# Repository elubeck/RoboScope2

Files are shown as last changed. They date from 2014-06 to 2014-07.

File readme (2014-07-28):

Steps for installing

Jython Plugin
- Jython standalone jar file (v2.7b1 tested) needs to be moved to /plugins/Micro-Manager
- JythonMMPlugin.jar (tested with jython v.27b1 and Micro-Manager-1.4.17,1.4.18) needs to be moved to /mmplugins/
- jythonconsole directory needs to be moved to /plugins/Micro-Manager

If all this works you should see a jython console in the plugins dropdown in micromanager.  If should open and run just fine.
In the future this should be replaced by ipython.  It'll make debugging easier.

The firmware should be uploaded

Notes:
    - Tried jython v2.7b2.  Didn't work.

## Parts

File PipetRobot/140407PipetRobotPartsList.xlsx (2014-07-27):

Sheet: Digikey
what | catalog no | how many | from where | how much each | total
3d printer fan | 1053-1208-ND | 4 | digikey | 9.98 | 39.92

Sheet: Mcmaster
what | catalog no | how many | from where | how much each | total
M3 6mm | 94500A221 | 1 | mcmaster | 5.77 | 5.77
M3 8mm | 94500A222 | 1 | mcmaster | 5.9 | 5.9
M5 10mm | 92095A208 | 1 | mcmaster | 11.98 | 11.98
M4 10mm | 94500A227 | 1 | mcmaster | 7.54 | 7.54
M6 | 92095A224 | 1 | mcmaster | 8.5 | 8.5
washer | 91090A108 | 1 | mcmaster | 3.9 | 3.9
20mm double | 5537T111 6 ft | 1 | mcmaster | 26.1 | 26.1
20mm double | 5537T111 2 ft | 1 | mcmaster | 11.23 | 11.23
1/4 in shaft 9" | 6061K21 | 2 | mcmaster | 4.55 | 9.1
3/8 shaft 1 ft | 6061K32 | 2 | mcmaster | 6.18 | 12.36
3/8 shaft 16" | 6061K424 | 2 | mcmaster | 9.16 | 18.32
1/4 bushing | 6381K415 | 3 | mcmaster | 1.48 | 4.44
3/8 bushing | 6381K453 | 6 | mcmaster | 1.88 | 11.28
20 mm single | 5537T101 6 ft | 1 | mcmaster | 17.19 | 17.19
 |  |  |  | total | 110.02

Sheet: Amazon
what | catalog no | how many | from where | how much each | total
endstops | B00G2E6UZC | 1 | amazon | 11 | 11
gt2 pulley | B00GNWMTWG | 3 | amazon | 5.8 | 17.4
gt2 belt 5m | B00F2IQNX8 | 1 | amazon | 20 | 20
nema 17 | B00C4P382G | 3 | amazon | 22 | 66
24v power supply | B00IF93H6W | 1 | amazon | 46 | 46
1/8" aluminum sheet | B00BO78RCQ | 1 | amazon | 11.52 | 11.52
 |  |  |  | total | 171.92

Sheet: Adafruit
what | catalog no | how many | from where | how much each | total
t nuts | 1158 | 2 | adafruit | 9.95 | 19.9

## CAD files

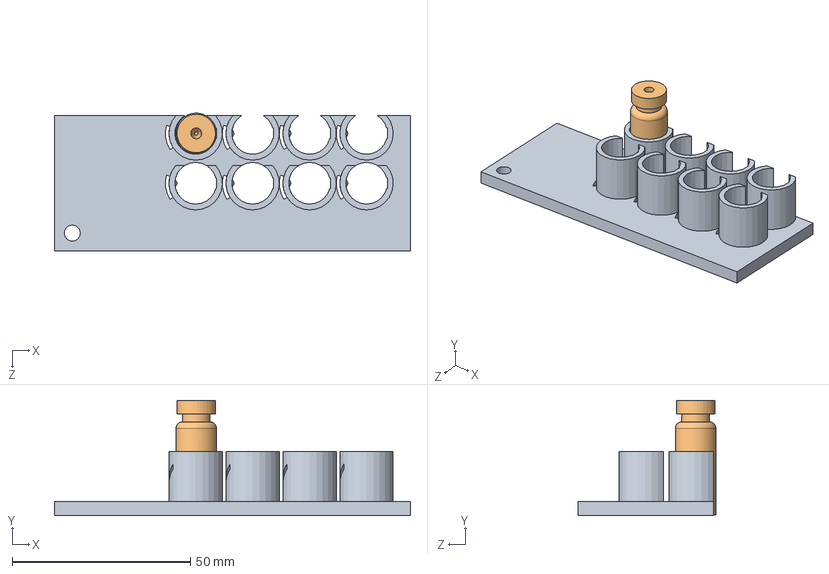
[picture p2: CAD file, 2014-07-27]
PipetRobot/vialholder/Assem1.SLDASM
100.0 x 32.3 x 38.7 mm
vialrack
plasticvial

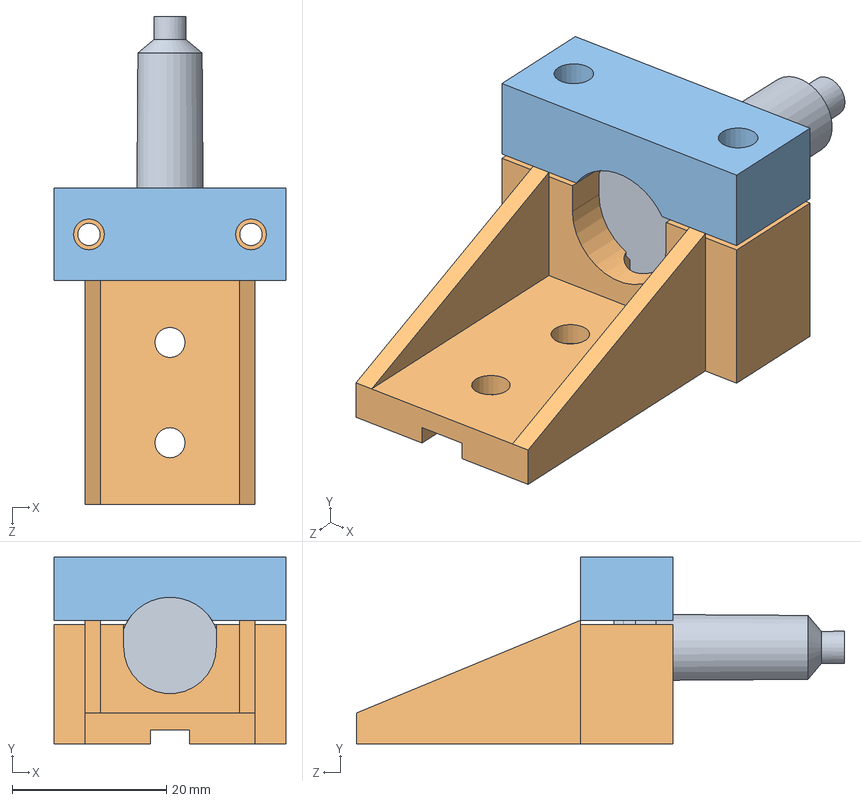
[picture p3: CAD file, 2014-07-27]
PipetRobot/syringe/purplecolumnholder.SLDASM
30.0 x 24.2 x 63.2 mm
qiagen_purple_column
purpleColumnHolder
purplecolumnclamper

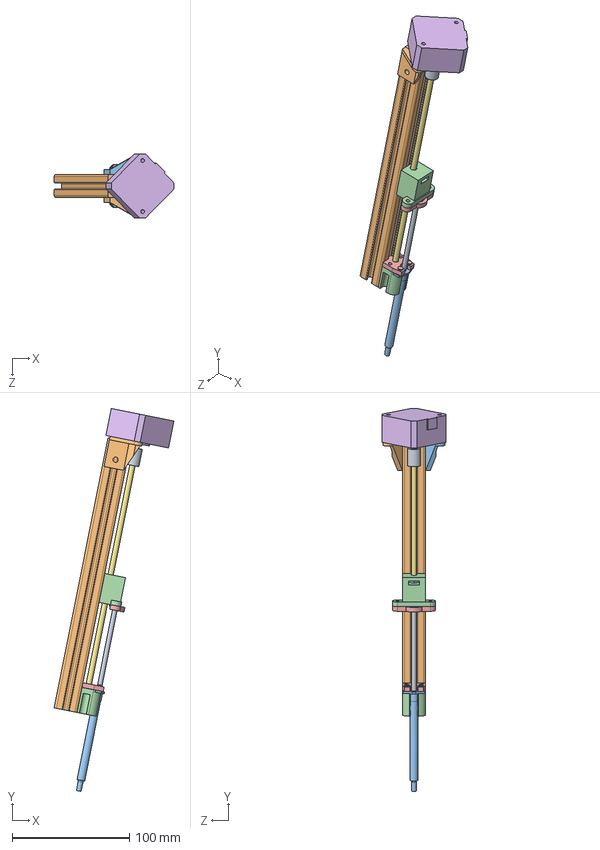
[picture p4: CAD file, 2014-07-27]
PipetRobot/syringe/syringeassembly.SLDASM
102.1 x 326.2 x 54.4 mm
syringeplunger
AluminumExtrusion
1mlsyringe
syringeholderbottom
syringeholdertop
smallstepper
Part3^syringeassembly
Part2^syringeassembly x 2
Part6^syringeassembly
Part7^syringeassembly
MirrorPart7^syringeassembly
pistonholder
Part1^syringeassembly

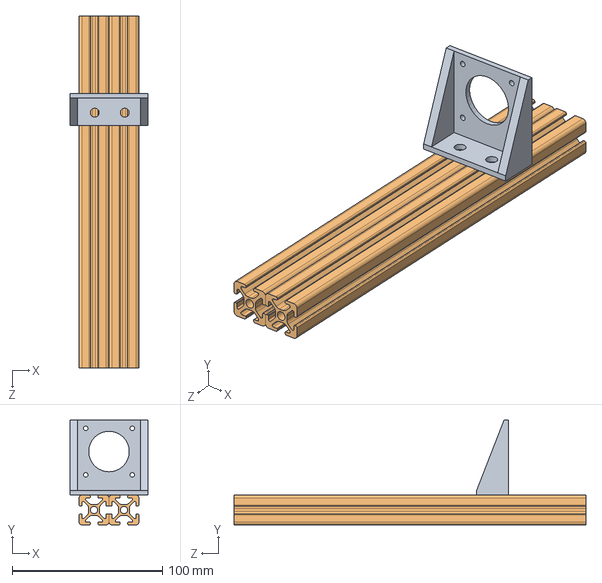
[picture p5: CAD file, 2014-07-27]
PipetRobot/Assem2.SLDASM
52.0 x 70.0 x 234.6 mm
steppermountlonger
AluminumExtrusion x 2

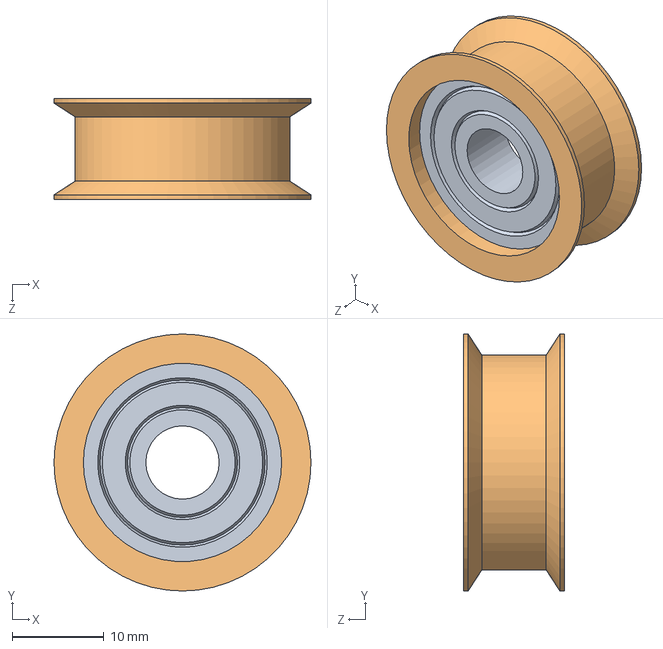
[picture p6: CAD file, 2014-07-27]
PipetRobot/skatepulley.SLDASM
28.0 x 28.0 x 11.0 mm
SkateBearing
skatepulley

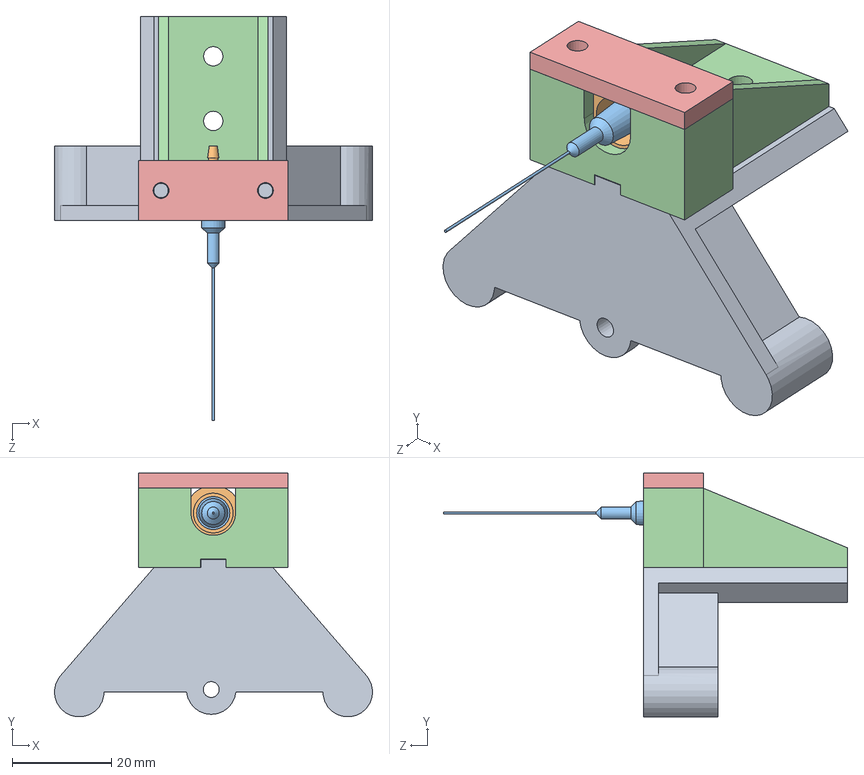
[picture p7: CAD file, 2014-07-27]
PipetRobot/syringe/Assem1.SLDASM
64.0 x 49.0 x 81.3 mm
zsyringemount
needleluer
needle
luerholder
luerholderclamp

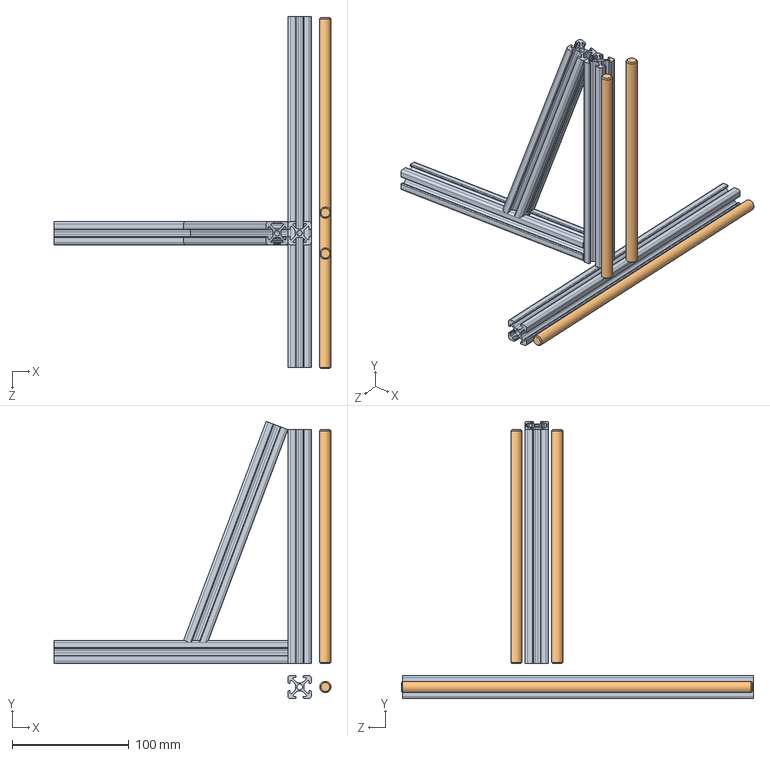
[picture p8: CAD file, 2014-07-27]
PipetRobot/Robot.SLDASM
236.8 x 237.0 x 301.0 mm
AluminumExtrusion x 4
ThreeEighthsRod x 3

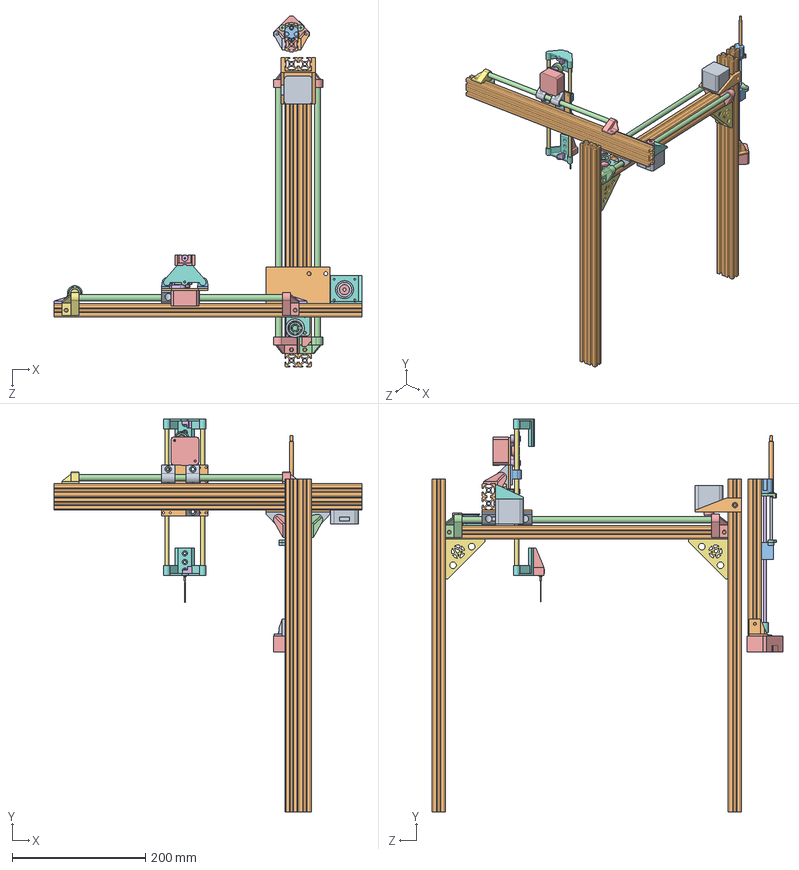
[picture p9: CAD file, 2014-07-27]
PipetRobot/autopettor.SLDASM
462.0 x 589.9 x 527.1 mm
NEMA17 x 2
AluminumExtrusion x 9
BronzeBushing x 6
ThreeEighthsRod x 4
CornerRodClamp x 4
Part4^autopettor x 2
quarterInchShaft9in x 2
quarterInchBearing x 3
bearingmountflat x 6
Part8^autopettor
Part9^autopettor x 3
SkateBearing x 4
GT2pulley x 3
Part12^autopettor
CornerRodClampCutout
steppermount
beltTrap
steppermountlonger
beltTrapTop
CornerRodClampWithTensioner
beltTrapTensioner
beltTrapTensioner2 x 3
Part3^autopettor x 4
zsyringemount x 2
syringeplunger
1mlsyringe
syringeholderbottom
syringeholdertop
smallstepper x 2
Part3^syringeassembly
Part2^syringeassembly x 2
Part6^syringeassembly
Part7^syringeassembly
MirrorPart7^syringeassembly
pistonholder
Part1^syringeassembly
luerholder
needleluer
needle
Part1^autopettor
skatepulley
Part2^autopettor

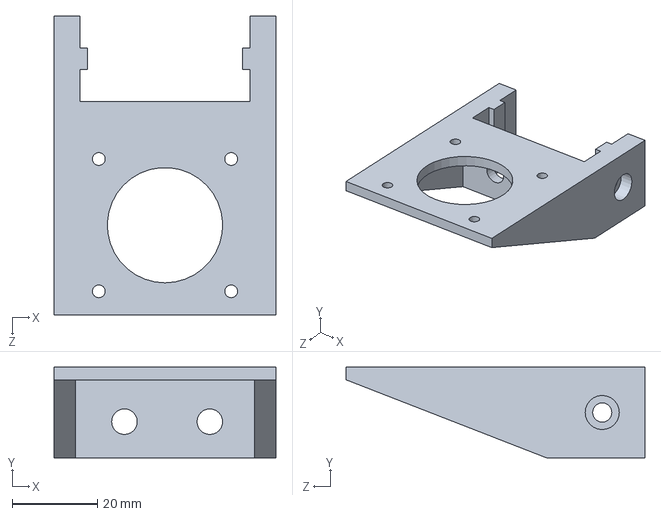
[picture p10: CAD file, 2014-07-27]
PipetRobot/steppermountlonger.sldprt
52.0 x 21.3 x 70.0 mm

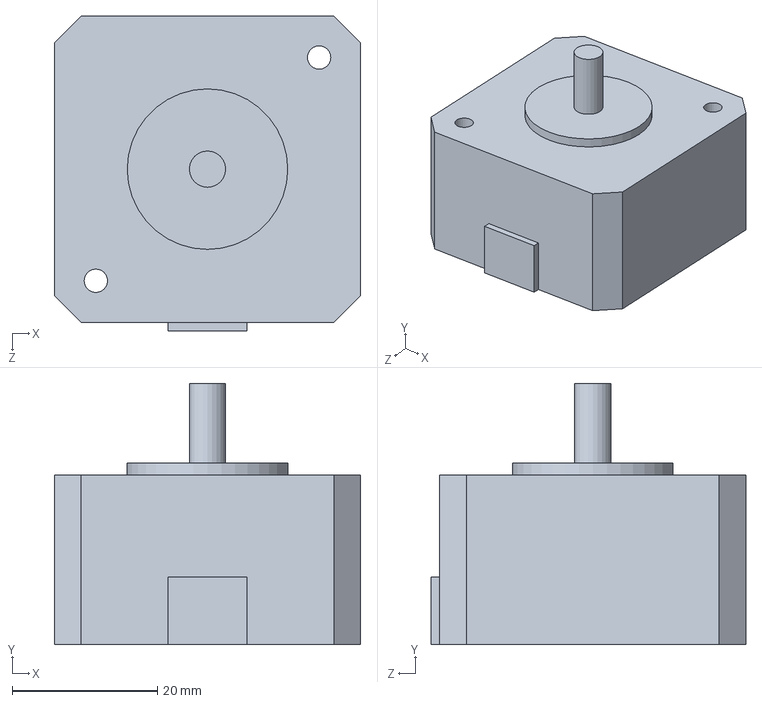
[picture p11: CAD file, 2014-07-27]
PipetRobot/syringe/smallstepper.SLDPRT
42.2 x 36.0 x 43.4 mm

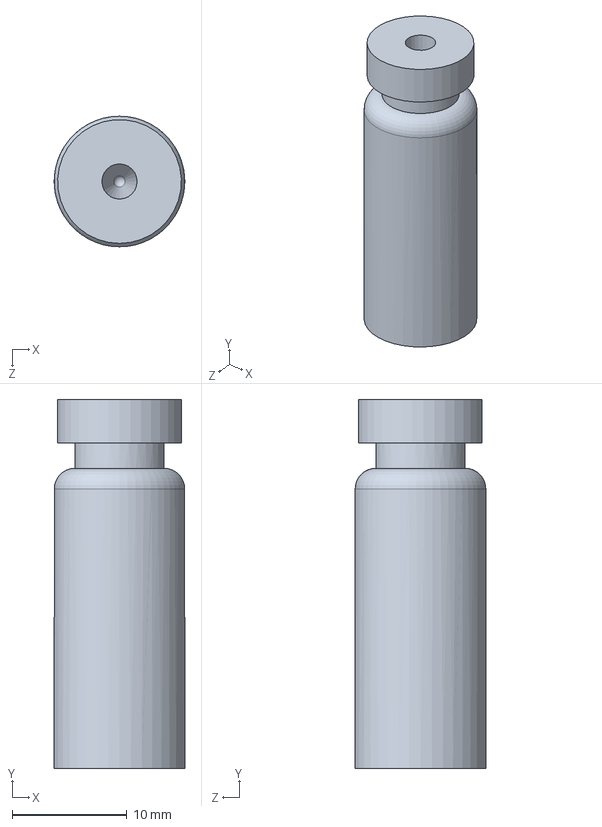
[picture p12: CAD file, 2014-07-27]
PipetRobot/vialholder/plasticvial.SLDPRT
11.4 x 32.2 x 11.4 mm

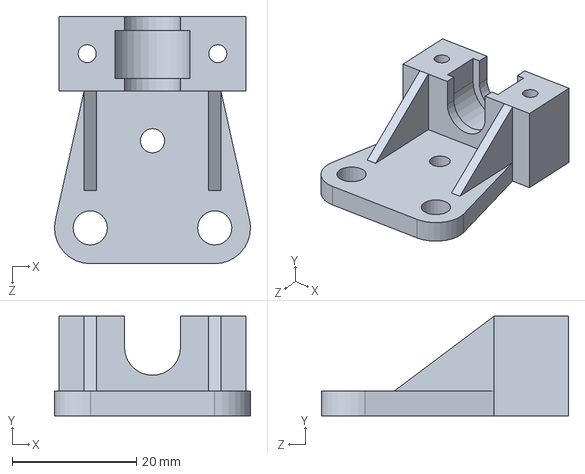
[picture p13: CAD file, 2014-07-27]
PipetRobotv2/luerholdershapeoko.sldprt
31.5 x 16.0 x 39.8 mm

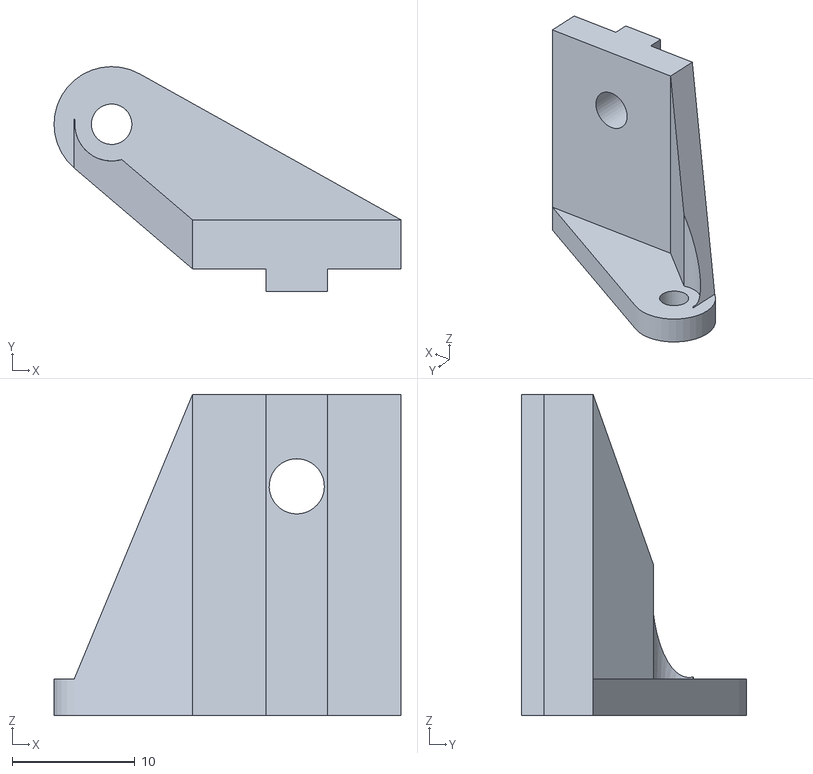
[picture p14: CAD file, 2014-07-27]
PipetRobot/syringe/Mirrorsteppermount.STL
28.3 x 18.3 x 26.2

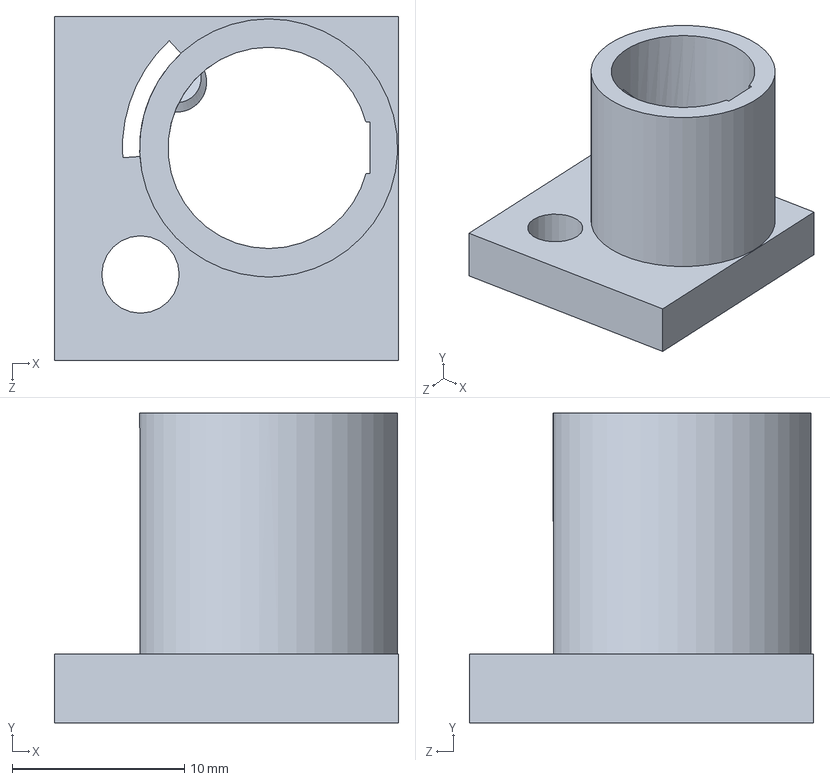
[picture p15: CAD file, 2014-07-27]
PipetRobot/vialholder/vialracksingle.SLDPRT
20.0 x 18.0 x 20.0 mm

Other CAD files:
PipetRobot/NeedleLuerHolder.sldasm
PipetRobot/steppermount.sldprt
PipetRobot/xaxisbearing.STL
PipetRobot/bearingmountflat.sldprt
PipetRobot/5537T104.SLDPRT
PipetRobot/57105K13pulley.SLDPRT
PipetRobot/AluminumExtrusion.sldprt
PipetRobot/CornerRodClamp.sldprt
PipetRobot/CornerRodClampCutout.sldprt
PipetRobot/CornerRodClampWithTensioner.sldprt
PipetRobot/GT2pulley.sldprt
PipetRobot/Imported Components/NeedleLuerHolder/luerholder.ipt
PipetRobot/ThreeEighthsRod.sldprt
PipetRobot/bearingmount.sldprt
PipetRobot/beltTrap.sldprt
PipetRobot/beltTrapTensioner.STL
PipetRobot/beltTrapTensioner.sldprt
PipetRobot/beltTrapTensioner2.sldprt
PipetRobot/beltTrapTop.STL
PipetRobot/beltTrapTop.sldprt
PipetRobot/beltTrapmid.STL
PipetRobot/epP200.SLDPRT
PipetRobot/m3screw.SLDPRT
PipetRobot/pulleymount.STL
PipetRobot/quarterInchBearing.sldprt
PipetRobot/quarterInchShaft9in.sldprt
PipetRobot/rainP200.SLDPRT
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

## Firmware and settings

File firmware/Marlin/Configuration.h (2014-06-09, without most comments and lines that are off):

#define CONFIGURATION_H
#define STRING_VERSION_CONFIG_H __DATE__ " " __TIME__ // build date and time
#define STRING_CONFIG_H_AUTHOR "(none, default config)" // Who made the changes.
#define SERIAL_PORT 0
#define BAUDRATE 115200
#define MOTHERBOARD 65
#define EXTRUDERS 1
#define POWER_SUPPLY 1
#define TEMP_SENSOR_0 0
#define TEMP_SENSOR_1 0
#define TEMP_SENSOR_2 0
#define TEMP_SENSOR_BED 0
#define MAX_REDUNDANT_TEMP_SENSOR_DIFF 10
#define TEMP_RESIDENCY_TIME 10  // (seconds)
#define TEMP_HYSTERESIS 3       // (degC) range of +/- temperatures considered "close" to the target one
#define TEMP_WINDOW     1       // (degC) Window around target to start the residency timer x degC early.
#define HEATER_0_MINTEMP 0
#define HEATER_1_MINTEMP 5
#define HEATER_2_MINTEMP 5
#define BED_MINTEMP 0
#define HEATER_0_MAXTEMP 800
#define HEATER_1_MAXTEMP 275
#define HEATER_2_MAXTEMP 275
#define BED_MAXTEMP 300
#define BANG_MAX 255 // limits current to nozzle while in bang-bang mode; 255=full current
#define PID_MAX 20 // limits current to nozzle while PID is active (see PID_FUNCTIONAL_RANGE below); 255=full current
#define MAX_BED_POWER 100 // limits duty cycle to bed; 255=full current
#define EXTRUDE_MINTEMP 0
#define EXTRUDE_MAXLENGTH (X_MAX_LENGTH+Y_MAX_LENGTH) //prevent extrusion of very large distances.
#define ENDSTOPPULLUPS // Comment this out (using // at the start of the line) to disable the endstop pullup resistors
  #define ENDSTOPPULLUP_XMAX
  #define ENDSTOPPULLUP_YMAX
  #define ENDSTOPPULLUP_ZMAX
  #define ENDSTOPPULLUP_XMIN
  #define ENDSTOPPULLUP_YMIN
  #define ENDSTOPPULLUP_ZMIN
const bool X_MIN_ENDSTOP_INVERTING = true; // set to true to invert the logic of the endstop.
const bool Y_MIN_ENDSTOP_INVERTING = true; // set to true to invert the logic of the endstop.
const bool Z_MIN_ENDSTOP_INVERTING = true; // set to true to invert the logic of the endstop.
const bool X_MAX_ENDSTOP_INVERTING = true; // set to true to invert the logic of the endstop.
const bool Y_MAX_ENDSTOP_INVERTING = true; // set to true to invert the logic of the endstop.
const bool Z_MAX_ENDSTOP_INVERTING = true; // set to true to invert the logic of the endstop.
const bool E_MIN_ENDSTOP_INVERTING = true; //dreyedit
#if defined(COREXY) && !defined(DISABLE_MAX_ENDSTOPS)
  #define DISABLE_MAX_ENDSTOPS
#endif
#define X_ENABLE_ON 0
#define Y_ENABLE_ON 0
#define Z_ENABLE_ON 0
#define E_ENABLE_ON 0 // For all extruders
#define DISABLE_X false
#define DISABLE_Y false
#define DISABLE_Z false
#define DISABLE_E false // For all extruders
#define INVERT_X_DIR false    // for Mendel set to false, for Orca set to true
#define INVERT_Y_DIR false    // for Mendel set to true, for Orca set to false
#define INVERT_Z_DIR true     // for Mendel set to false, for Orca set to true
#define INVERT_E0_DIR true   // for direct drive extruder v9 set to true, for geared extruder set to false
#define INVERT_E1_DIR false    // for direct drive extruder v9 set to true, for geared extruder set to false
#define INVERT_E2_DIR false   // for direct drive extruder v9 set to true, for geared extruder set to false
#define X_HOME_DIR -1
#define Y_HOME_DIR -1
#define Z_HOME_DIR 1
#define E_HOME_DIR -1 //home the e axis!! dreyedit
#define min_software_endstops true // If true, axis won't move to coordinates less than HOME_POS.
#define max_software_endstops true  // If true, axis won't move to coordinates greater than the defined lengths below.
#define X_MAX_POS 237
#define X_MIN_POS 0
#define Y_MAX_POS 160
#define Y_MIN_POS 0
#define Z_MAX_POS 86
#define Z_MIN_POS 0
#define X_MAX_LENGTH (X_MAX_POS - X_MIN_POS)
#define Y_MAX_LENGTH (Y_MAX_POS - Y_MIN_POS)
#define Z_MAX_LENGTH (Z_MAX_POS - Z_MIN_POS)
#define ENABLE_AUTO_BED_LEVELING // Delete the comment to enable (remove // at the start of the line)
      #define ABL_PROBE_PT_1_X 51
      #define ABL_PROBE_PT_1_Y 46
      #define ABL_PROBE_PT_2_X 120
      #define ABL_PROBE_PT_2_Y 69
      #define ABL_PROBE_PT_3_X 80
      #define ABL_PROBE_PT_3_Y 92
  #define X_PROBE_OFFSET_FROM_EXTRUDER 0
  #define Y_PROBE_OFFSET_FROM_EXTRUDER 0
  #define Z_PROBE_OFFSET_FROM_EXTRUDER 0
  #define Z_RAISE_BEFORE_HOMING 50       // (in mm) Raise Z before homing (G28) for Probe Clearance.
  #define XY_TRAVEL_SPEED 800         // X and Y axis travel speed between probes, in mm/min
  #define Z_RAISE_BEFORE_PROBING 50    //How much the extruder will be raised before traveling to the first probing point.
  #define Z_RAISE_BETWEEN_PROBINGS 50  //How much the extruder will be raised when traveling from between next probing points
  #define Z_SAFE_HOMING   // This feature is meant to avoid Z homing with probe outside the bed area.
    #define Z_SAFE_HOMING_X_POINT (X_MAX_LENGTH/2)    // X point for Z homing when homing all axis (G28)
    #define Z_SAFE_HOMING_Y_POINT (Y_MAX_LENGTH/2)    // Y point for Z homing when homing all axis (G28)
#define MANUAL_X_HOME_POS 0
#define MANUAL_Y_HOME_POS 0
#define MANUAL_Z_HOME_POS 0
#define NUM_AXIS 4 // The axis order in all axis related arrays is X, Y, Z, E
#define HOMING_FEEDRATE {1000, 1000, 1000, 1000}  // set the homing speeds (mm/min)
#define DEFAULT_AXIS_STEPS_PER_UNIT   {160.476,160.476,320.476,760*1.1}  // default steps per unit for Ultimaker
#define DEFAULT_MAX_FEEDRATE          {500, 500, 500, 500}    // (mm/sec)
#define DEFAULT_MAX_ACCELERATION      {50,100,900,10000}    // X, Y, Z, E maximum start speed for accelerated moves. E default values are good for Skeinforge 40+, for older versions raise them a lot.
#define DEFAULT_ACCELERATION          3000    // X, Y, Z and E max acceleration in mm/s^2 for printing moves
#define DEFAULT_RETRACT_ACCELERATION  3000   // X, Y, Z and E max acceleration in mm/s^2 for retracts
#define DEFAULT_XYJERK                2.0    // (mm/sec)
#define DEFAULT_ZJERK                 20.0// (mm/sec)
#define DEFAULT_EJERK                 5.0    // (mm/sec)
#define CUSTOM_M_CODES
  #define CUSTOM_M_CODE_SET_Z_PROBE_OFFSET 851
  #define Z_PROBE_OFFSET_RANGE_MIN -15
  #define Z_PROBE_OFFSET_RANGE_MAX -5
#define PLA_PREHEAT_HOTEND_TEMP 180
#define PLA_PREHEAT_HPB_TEMP 70
#define PLA_PREHEAT_FAN_SPEED 255   // Insert Value between 0 and 255
#define ABS_PREHEAT_HOTEND_TEMP 240
#define ABS_PREHEAT_HPB_TEMP 100
#define ABS_PREHEAT_FAN_SPEED 255   // Insert Value between 0 and 255
#define FAST_PWM_FAN
#define FAN_SOFT_PWM
#define SOFT_PWM_SCALE 2
#include "Configuration_adv.h"
#include "thermistortables.h"

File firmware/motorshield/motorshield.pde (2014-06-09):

#include <Wire.h>
#include <Adafruit_MotorShield.h>
#include "utility/Adafruit_PWMServoDriver.h"

Adafruit_MotorShield AFMS = Adafruit_MotorShield();
Adafruit_DCMotor *motor1 = AFMS.getMotor(1);
Adafruit_DCMotor *motor2 = AFMS.getMotor(2);
Adafruit_DCMotor *solenoid1 = AFMS.getMotor(3);
Adafruit_DCMotor *solenoid2 = AFMS.getMotor(4);
Adafruit_DCMotor *motor;

int pin = 0;

void setup() {
  Serial.begin(19200);
  AFMS.begin();
  motor1->setSpeed(255);
  motor2->setSpeed(255);
  solenoid1->setSpeed(255);
  solenoid2->setSpeed(255);
}

void loop() {
 while (Serial.available()) {
   int inByte_0 = Serial.read();
   int inByte_1 = Serial.read();
   switch (inByte_0) {
     case 0: motor = motor1;
     case 1: motor = motor2;
     case 2: motor = solenoid1;
     case 3: motor = solenoid2;
   }
   Serial.println(inByte_0 - 48);
   Serial.println(inByte_1);
 } 
}

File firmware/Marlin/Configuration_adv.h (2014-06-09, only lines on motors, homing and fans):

#define CONTROLLERFAN_PIN -1 //Pin used for the fan to cool controller (-1 to disable)
#define EXTRUDER_0_AUTO_FAN_PIN   -1
#define EXTRUDER_1_AUTO_FAN_PIN   -1
#define EXTRUDER_2_AUTO_FAN_PIN   -1
#define ENDSTOPS_ONLY_FOR_HOMING // If defined the endstops will only be used for homing
#define X_HOME_RETRACT_MM 5
#define Y_HOME_RETRACT_MM 5
#define Z_HOME_RETRACT_MM 2
#define MICROSTEP1 LOW,LOW
#define MICROSTEP2 HIGH,LOW
#define MICROSTEP4 LOW,HIGH
#define MICROSTEP8 HIGH,HIGH
#define MICROSTEP16 HIGH,HIGH
#define MICROSTEP_MODES {16,16,16,16,16} // [1,2,4,8,16]
#define DIGIPOT_MOTOR_CURRENT {135,135,135,135,135} // Values 0-255 (RAMBO 135 = ~0.75A, 185 = ~1A)
#define DIGIPOT_I2C_MOTOR_CURRENTS {1.0, 1.0, 1.0, 1.0, 1.0, 1.0, 1.0, 1.0}

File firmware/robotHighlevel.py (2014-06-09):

#this code controls the robot and converts high level commands (where to go)
#into low level commands (move to this co-ordinate)
#from __future__ import division
import time
import math as m
import random
import copy as c
import sys


#from stageCalibration import *

class MMSerial:

    def write(self, code):
        self.core.setSerialPortCommand("Robot", code, "\n")
    
    def readline(self):
        try:
            return self.core.getSerialPortAnswer("Robot", "\n")+"\n"
        except:
            return ""
        
    def close(self):
        pass

    def __init__(self, core, port, baudrate):
        self.core = core
        self.core.loadDevice("Robot", "SerialManager", port.upper())
        self.core.setProperty("Robot", "BaudRate", str(baudrate))
        self.core.initializeDevice("Robot")

def dc(something):
    """wrapper for deep copy"""
    return c.deepcopy(something)

class Robot:
    def __init__(self,serialPort,baudrate,timeout=200, mmcore=False,home=True,syringe = True):
        """opens a serial channel and begins communication"""
        if mmcore is not False:
            # Trys to load micromanager core as serial lib
            self.robolink = MMSerial(mmcore, serialPort, baudrate)
        else:
            import serial
            self.robolink = serial.Serial(serialPort, baudrate, timeout=200)
        #logfile = open("C:\\Users\\Olympus2User\\Desktop\\firmware\\logfile.txt","a")
        #logfile.write("ROBOT INITIALIZED BEEP BOOP\n")
        #logfile.close()
        
        time.sleep(3)
        self.modx = 0.0
        self.mody = 0.0
        self.modz = 0.0
        self.stageposx = 0.0
        self.stageposy = 0.0
        self.uLpermm = 3.5
        if(home):
            self.homeNow(syringe=syringe)
        
    def homeNow(self,syringe = True):
        self.arbGcode("G28 Z0")
        self.arbGcode("G1 Z60")
        self.arbGcode("G28 X0")
        self.arbGcode("G28 Y0")
        self.arbGcode("G28 Z0")
        self.arbGcode("G1 Z60")
        if(syringe):
            self.homeSyringe()
        
    def setOffset(self, x, y):
        """sets a stage offset for stage co-ordination"""
        self.stageposx = x
        self.stageposy = y
        
    def gotoWell(self,welldef,well,feedrate=1000):
        """tells the robot to move to the top coordinate of
        a well"""
        curpos = self.getCoords();
        welldef.setOffset([self.stageposx,self.stageposy])
        XYgoal = welldef.wellPos(well)
        Zgoal = welldef.zposTOP

        if(curpos[2] < Zgoal):
            self.makeMove([None,None,Zgoal,None],feedrate)
        self.makeMove([XYgoal[0],XYgoal[1],None,None],feedrate)
        self.makeMove([None,None,Zgoal,None],feedrate)
        
    def aspirate(self,amount_uL,feedrate= 300):
        """how many microliters to suck in"""
        amount_mm = amount_uL/self.uLpermm
        currentPosition = self.getCoords()[3]
        self.arbGcode("G1 E{} F{}".format(currentPosition-amount_mm,feedrate))
    
    def dispense(self,amount_uL,feedrate=300):
        """how many microliters to spit out"""
        self.aspirate(-amount_uL,feedrate)
    def gotoBottom(self,microwell,feedrate=1000):
        self.makeMove([None,None,microwell.zposBOTTOM],feedrate)
    def gotoTop(self,microwell,feedrate=1000):
        self.makeMove([None,None,microwell.zposTOP],feedrate)
    def cleanSyringe(self,microwell,waterwell="A2",meohwell="A3",closedwell="A1",feedrate=1000):
        """goes to waterwell, then activates the peristaltic pump, then
        goes to meohwell, and activates the peristaltic pump. Finally,
        goes to air and activates persitaltic pump while also zeroing the
        syringe"""
        self.gotoWell(microwell,waterwell,feedrate)
        self.enablePump()
        self.gotoBottom(microwell,feedrate);
        self.aspirate(1000,feedrate=1000);
        self.gotoTop(microwell,feedrate);
        self.disablePump()
        self.wait(3)
        self.gotoWell(microwell,meohwell,feedrate)
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

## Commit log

2014-06-11 Routine commit so i don't loose track of changes
2014-06-11 Recalibrated syringe
2014-06-18 Modified needle cal to not move stage.
2014-06-18 Added pipet robot v1 solidworks files
    [1032threadedRod.sldprt, 140407PipetRobotPartsList.xlsx, 1_6mltube.SLDPRT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]
2014-06-18 New Version of Luer lock holder for shapeoko2
    [luerholdershapeoko.sldprt]
2014-06-24 Testing to see if homeing is causing stalling problem.
